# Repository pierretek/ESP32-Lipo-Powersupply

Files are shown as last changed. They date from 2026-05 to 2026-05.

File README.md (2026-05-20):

# 3.7V Lipo Charger to 3.3V Power Supply 

A 3.7V LiPo battery charging circuit coupled with a buck-boost converter to provide steady **3.3V** for an **ESP32**

**View the [interactive BOM](https://pierretek.github.io/ESP32-Lipo-Powersupply/) here!**
 
## Features 
- Battery under-voltage and over-voltage protection **(2.800V - 4.275V)**
- Built-in buck-boost converter to provide a steady 3.3V to the ESP32
- A pair of 1*15 pin headers compatible with a `30-pin ESP32 Devkit V1` 
- `USB-C` port for charging, and `2.54mm JST-XH` connector for battery
- Can charge the lipo battery at **~485mA** while providing **~500mA** to the ESP32

> [!NOTE]
> To keep the ESP32’s pins accessible, use [stacking headers](https://www.aliexpress.com/item/1005008090018820.html) so the board can plug into a breadboard or another module underneath.

## Important Files
- KiCad project: `/kicad`
- JLCPCB production files: `/production_files`
- Gerbers: `/gerber`
  
## Key IC's
- **[BQ24070RHLR](https://jlcpcb.com/partdetail/TexasInstruments-BQ24070RHLR/C6514)** - main charging IC + power path management
  - [datasheet](https://www.lcsc.com/datasheet/C6514.pdf)
- **[BQ29700DSER](https://jlcpcb.com/partdetail/TexasInstruments-BQ29700DSER/C183096)** - battery protection IC
  - [datasheet](https://www.lcsc.com/datasheet/C183096.pdf)
- **[FS8205A](https://jlcpcb.com/partdetail/FUXINSEMI-FS8205A/C908265)** - dual mosfet
  - [datasheet](https://www.lcsc.com/datasheet/C908265.pdf)
- **[TPS63001DRCR](https://jlcpcb.com/partdetail/TexasInstruments-TPS63001DRCR/C28060)** - 3.3V buck-boost converter
  - [datasheet](https://www.lcsc.com/datasheet/C28060.pdf)

## Image Gallery
### Schematic (i know its messy)
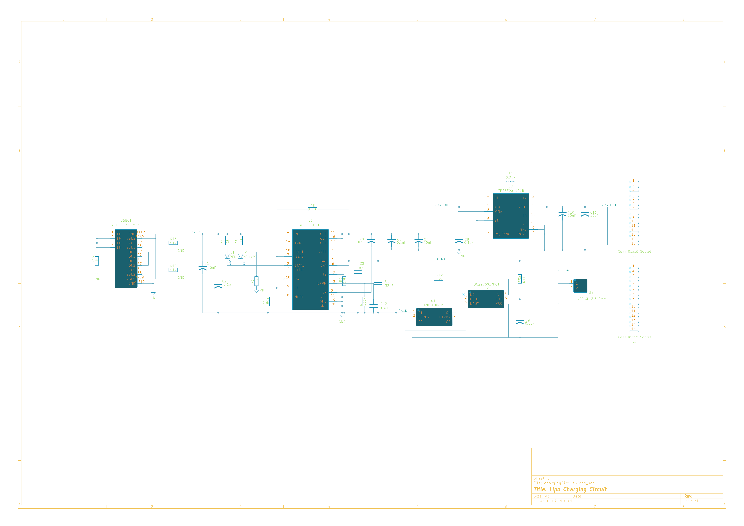
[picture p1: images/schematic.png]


### PCB top view 
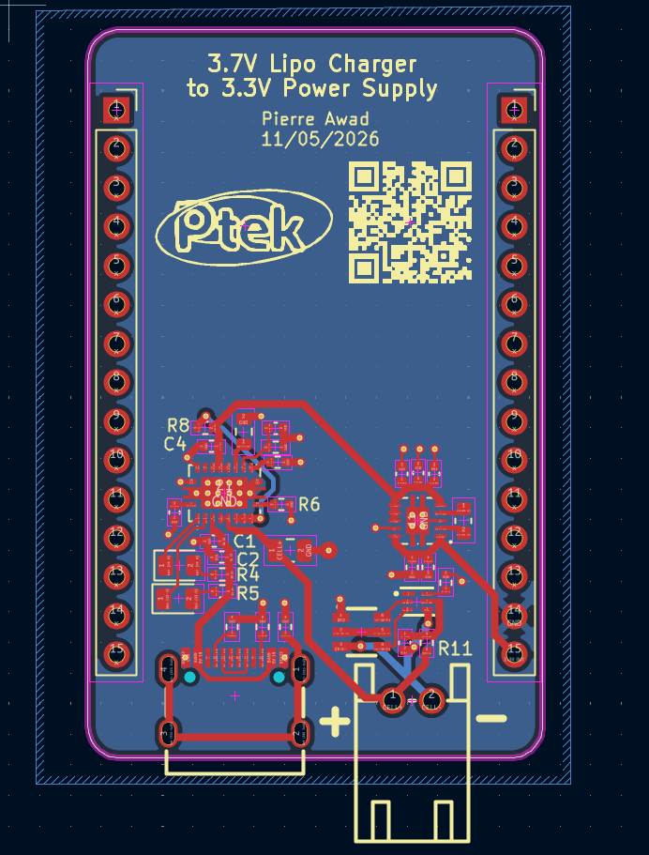
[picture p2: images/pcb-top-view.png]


### 3D view
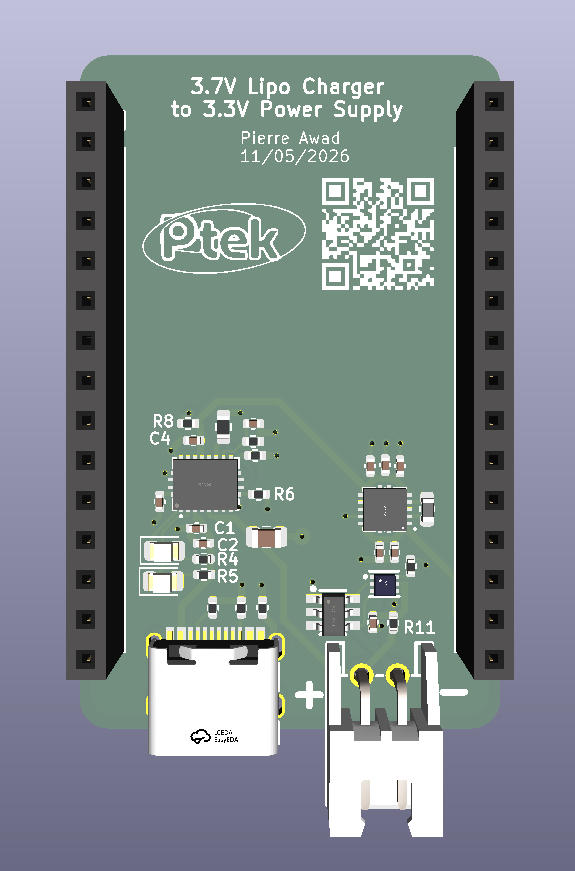
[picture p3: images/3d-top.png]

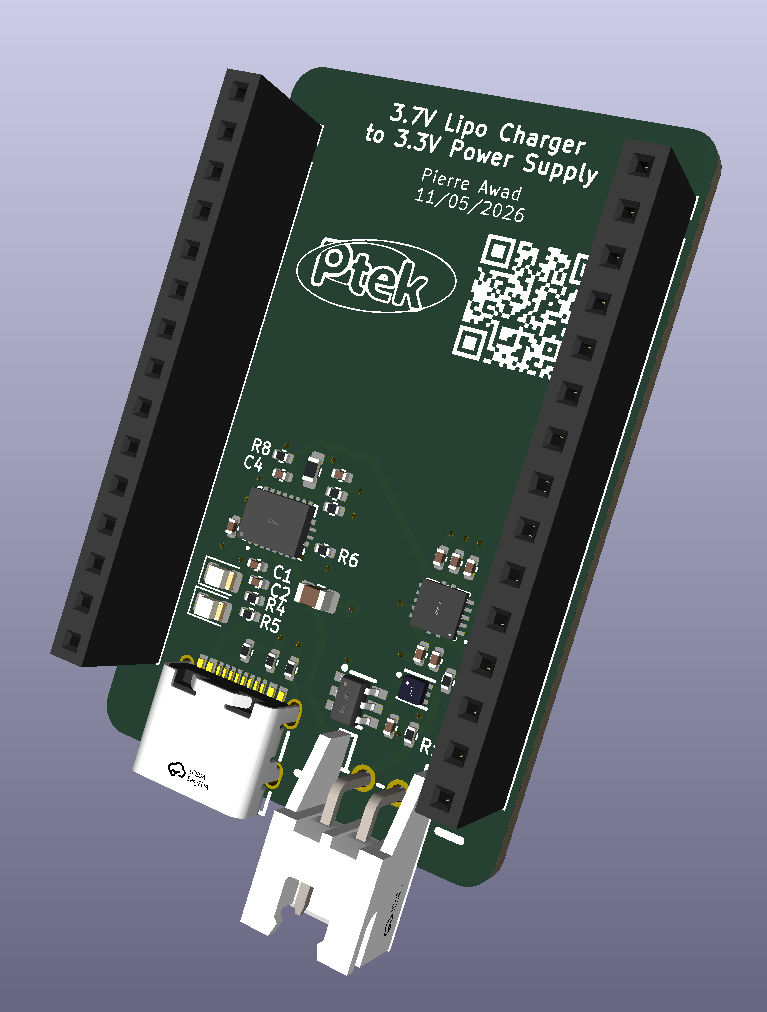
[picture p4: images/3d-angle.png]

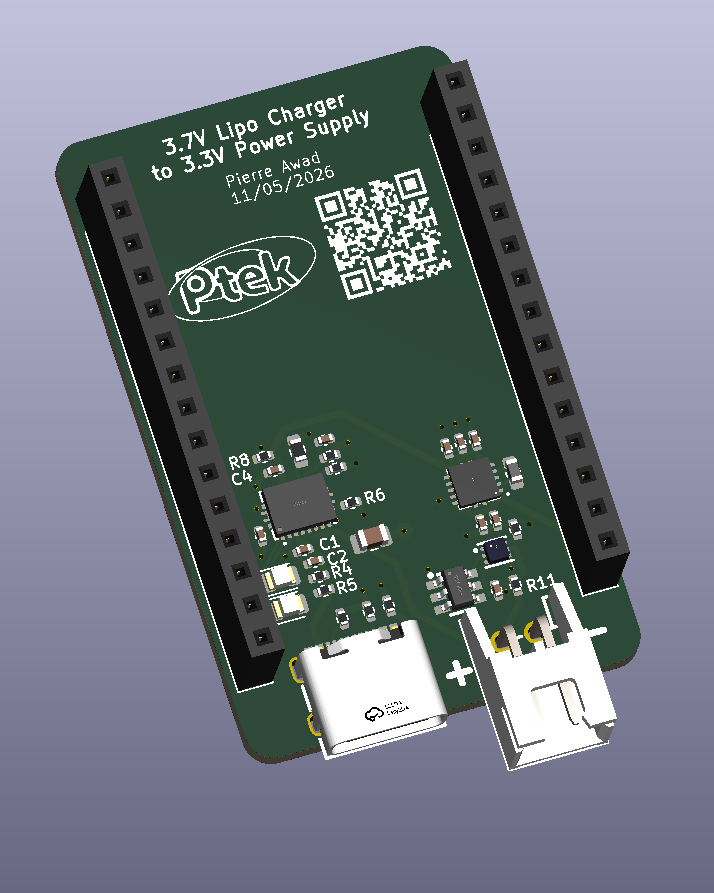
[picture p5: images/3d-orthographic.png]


## Credits / Tools Used
- KiCad 
- [kicad-jlcpcb-tools](https://github.com/bouni/kicad-jlcpcb-tools) (to generate the jlcpcb files)
- [InteractiveHtmlBom](https://github.com/openscopeproject/interactivehtmlbom) (for the [interactive html BOM](https://pierretek.github.io/ESP32-Lipo-Powersupply/))

_thanks for reading_

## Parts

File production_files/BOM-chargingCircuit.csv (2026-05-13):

Comment | Designator | Footprint | LCSC | Quantity
BQ24070_CHG | U1 | BQ24070RHLR | C6514 | 1
BQ29700_PROT | U2 | BQ29700DSER | C183096 | 1
FS8205A_DMOSFET | Q1 | FS8205A_C908265 | C908265 | 1
JST_XH_2.544mm | U4 | S2B-XH-A-_LF_SN | C157931 | 1
TPS63001DRCR | U3 | TPS63001DRCR | C28060 | 1
TYPE-C-31-M-12 | USBC1 | TYPE-C-31-M-12 | C165948 | 1
10nF | C12 | C_0402_1005Metric |  | 1
100k | R10 | R_0402_1005Metric |  | 1
10uF | C11 | C_0402_1005Metric |  | 1
0.1uF | C9 | C_0402_1005Metric |  | 1
10uF | C10 | C_0402_1005Metric |  | 1
YELLOW | D2 | LED_0805_2012Metric |  | 1
0.1uF | C8 | C_0402_1005Metric |  | 1
50k | R7 | R_0603_1608Metric |  | 1
Conn_01x15_Socket | J2 | PinSocket_1x15_P2.54mm_Vertical |  | 1
0.1uF | C3 | C_0402_1005Metric |  | 1
2.2k | R12 | R_0402_1005Metric |  | 1
2.2uH | L1 | L_0603_1608Metric |  | 1
10uF | C1 | C_0402_1005Metric |  | 1
1k | R5 | R_0402_1005Metric |  | 1
5.1k | R14 | R_0402_1005Metric |  | 1
10k | R9 | R_0402_1005Metric |  | 1
2k | R6 | R_0402_1005Metric |  | 1
0.1uF | C4 | C_0402_1005Metric |  | 1
100k | R8 | R_0402_1005Metric |  | 1
Conn_01x15_Socket | J3 | PinSocket_1x15_P2.54mm_Vertical |  | 1
330 | R11 | R_0402_1005Metric |  | 1
RED | D1 | LED_0805_2012Metric |  | 1
5.1k | R13 | R_0402_1005Metric |  | 1
0.1uF | C2 | C_0402_1005Metric |  | 1
33uF | C5 | C_0805_2012Metric |  | 1
1M | R15 | R_0402_1005Metric |  | 1
10uF | C7 | C_0402_1005Metric |  | 1
0.1uF | C6 | C_0402_1005Metric |  | 1
1k | R4 | R_0402_1005Metric |  | 1

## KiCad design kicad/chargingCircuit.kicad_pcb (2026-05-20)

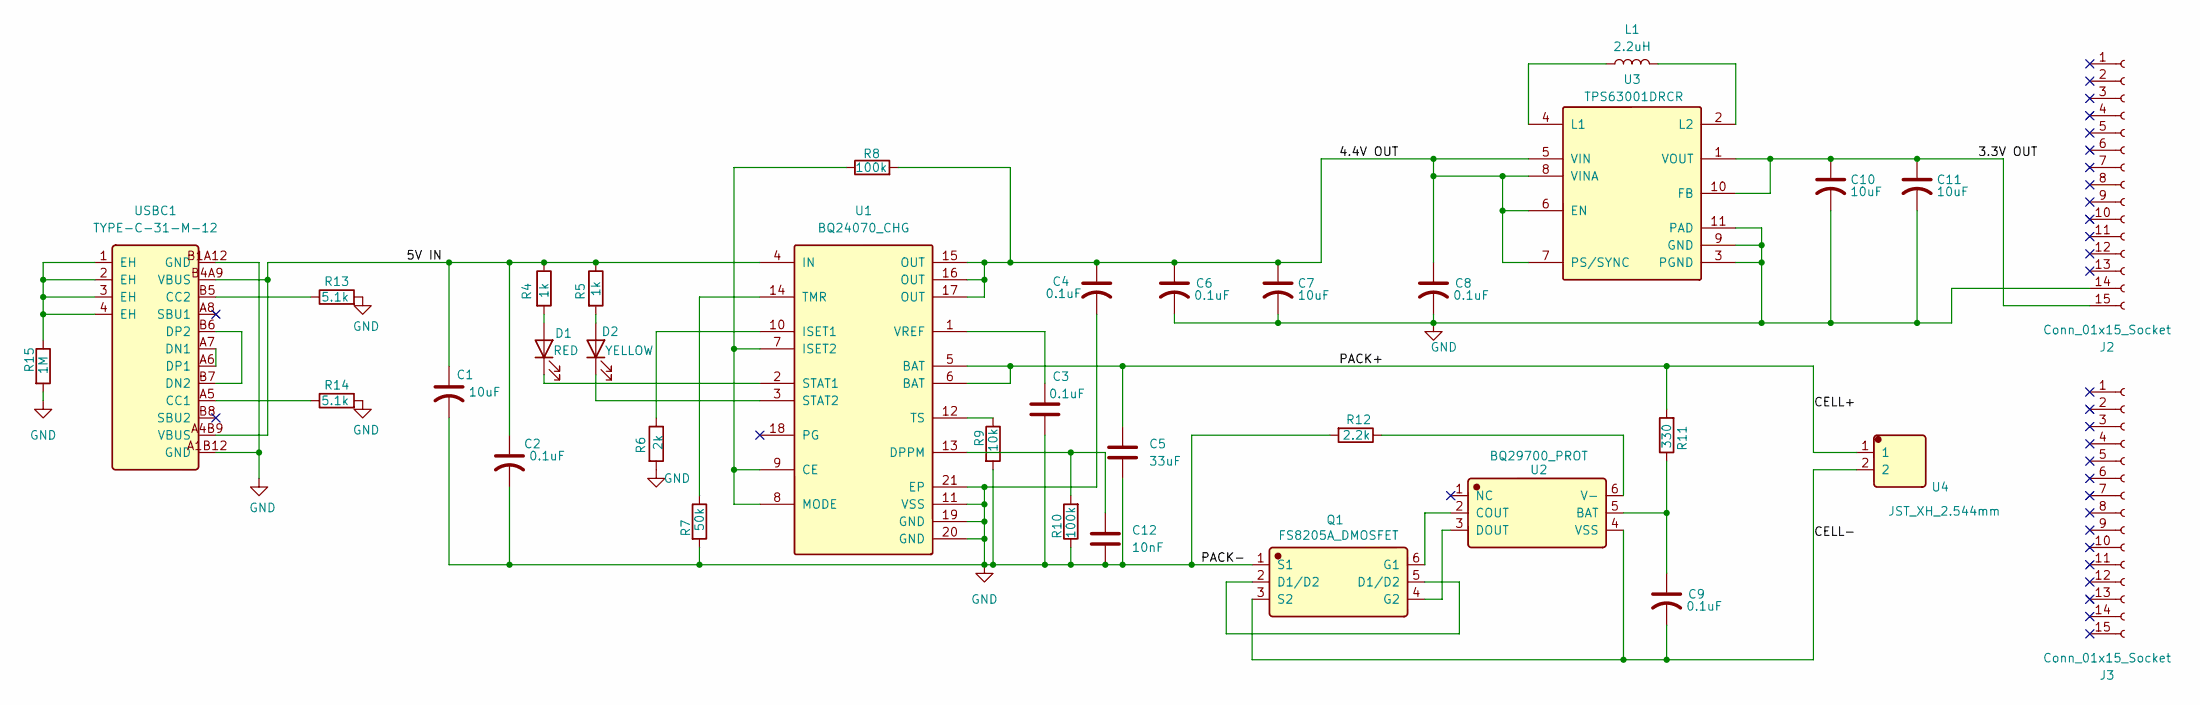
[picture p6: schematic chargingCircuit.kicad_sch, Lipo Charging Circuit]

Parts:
C1, C7, C10, C11: 10uF; C_0402_1005Metric; LCSC C15525
C2, C3, C4, C6, C8, C9: 0.1uF; C_0402_1005Metric; LCSC C1525
C5: 33uF; C_0805_2012Metric; LCSC C342307
C12: 10nF; C_0402_1005Metric; LCSC C15195
D1: RED; LED_0805_2012Metric; LCSC C2286
D2: YELLOW; LED_0805_2012Metric; LCSC C2290
J2, J3: Conn_01x15_Socket; PinSocket_1x15_P2.54mm_Vertical
L1: 2.2uH; L_0603_1608Metric; LCSC C6079477
Q1: FS8205A_DMOSFET; FS8205A_C908265; Manufacturer Part FS8205A; LCSC C908265
R4, R5: 1k; R_0402_1005Metric; LCSC C11702
R6: 2k; R_0402_1005Metric; LCSC C4109
R7: 50k; R_0603_1608Metric; LCSC C23184
R8, R10: 100k; R_0402_1005Metric; LCSC C25741
R9: 10k; R_0402_1005Metric; LCSC C25744
R11: 330; R_0402_1005Metric; LCSC C25104
R12: 2.2k; R_0402_1005Metric; LCSC C25879
R13, R14: 5.1k; R_0402_1005Metric; LCSC C25905
R15: 1M; R_0402_1005Metric; LCSC C26083
U1: BQ24070_CHG; BQ24070RHLR; Manufacturer Part BQ24070RHLR; LCSC C6514
U2: BQ29700_PROT; BQ29700DSER; Manufacturer Part BQ29700DSER; LCSC C183096
U3: TPS63001DRCR; Manufacturer Part TPS63001DRCR; LCSC C28060
U4: JST_XH_2.544mm; S2B-XH-A-_LF_SN; Manufacturer Part S2B-XH-A(LF)(SN); LCSC C157931
USBC1: TYPE-C-31-M-12; Manufacturer Part TYPE-C-31-M-12; LCSC C165948

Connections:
/3.3V OUT: C10.1, C11.1, J2.15, U3.1 (VOUT), U3.10 (FB)
/4.4V OUT: C4.1, C6.1, C7.1, C8.1, R8.2, U1.15 (OUT), U1.16 (OUT), U1.17 (OUT), U3.5 (VIN), U3.6 (EN), U3.7 (PS/SYNC), U3.8 (VINA)
/5V IN: C1.1, C2.1, R4.1, R5.1, U1.4 (IN), USBC1.A4B9 (VBUS), USBC1.B4A9 (VBUS)
/CELL+: C5.1, R11.2, U1.5 (BAT), U1.6 (BAT), U4.1
/CELL-: C9.2, Q1.3 (S2), U2.4 (VSS), U4.2
GND: C1.2, C2.2, C3.2, C4.2, C5.2, C6.2, C7.2, C8.2, C10.2, C11.2, C12.2, J2.14, Q1.1 (S1), R6.2, R7.2, R9.2, R10.1, R12.2, R13.2, R14.2, R15.2, U1.11 (VSS), U1.19 (GND), U1.20 (GND), U1.21 (EP), U3.3 (PGND), U3.9 (GND), U3.11 (PAD), USBC1.A1B12 (GND), USBC1.B1A12 (GND)
unnamed: D1.2 (A), R4.2
unnamed: D1.1 (K), U1.2 (STAT1)
unnamed: D2.2 (A), R5.2
unnamed: D2.1 (K), U1.3 (STAT2)
unnamed: Q1.2 (D1/D2), Q1.5 (D1/D2)
unnamed: Q1.6 (G1), U2.2 (COUT)
unnamed: Q1.4 (G2), U2.3 (DOUT)
unnamed: R15.1, USBC1.1 (EH), USBC1.2 (EH), USBC1.3 (EH), USBC1.4 (EH)
unnamed: R8.1, U1.7 (ISET2), U1.8 (MODE), U1.9 (CE)
unnamed: C12.1, R10.2, U1.13 (DPPM)
unnamed: R6.1, U1.10 (ISET1)
unnamed: R7.1, U1.14 (TMR)
unnamed: R9.1, U1.12 (TS)
unnamed: C3.1, U1.1 (VREF)
unnamed: C9.1, R11.1, U2.5 (BAT)
unnamed: R12.1, U2.6 (V-)
unnamed: L1.1, U3.4 (L1)
unnamed: L1.2, U3.2 (L2)
unnamed: R14.1, USBC1.A5 (CC1)
unnamed: R13.1, USBC1.B5 (CC2)
unnamed: USBC1.A6 (DP1), USBC1.A7 (DN1)
unnamed: USBC1.B6 (DP2), USBC1.B7 (DN2)

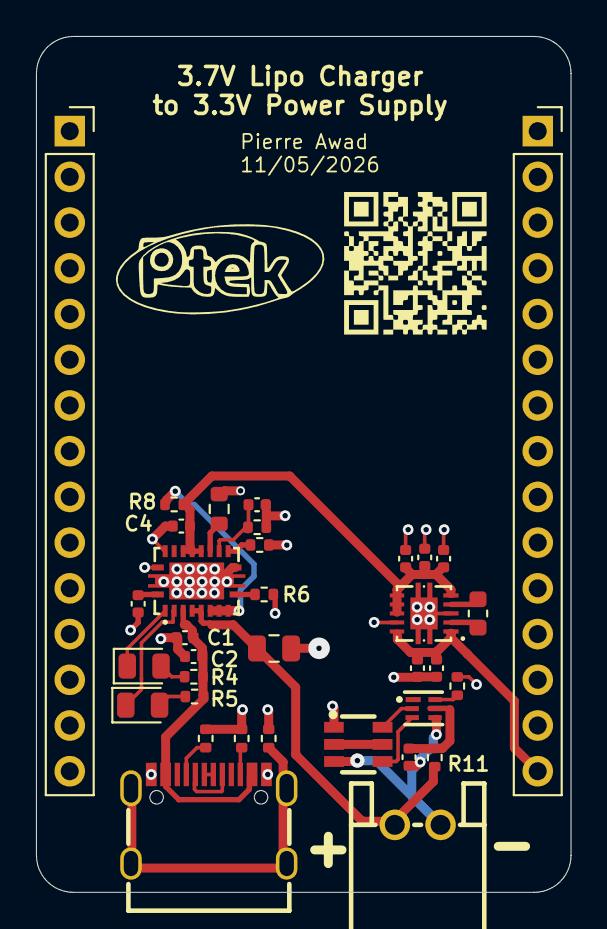
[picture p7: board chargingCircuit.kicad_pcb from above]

Board: 2 copper layers, 29.7 x 47.5 mm, 35 parts (0 on the bottom side), 28 nets.
